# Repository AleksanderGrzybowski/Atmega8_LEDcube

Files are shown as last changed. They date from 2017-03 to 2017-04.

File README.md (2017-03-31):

This is a 4x4x4 LED cube made just for the fun of creating it. Cube has been built using the cheapest LEDs on tme.eu, 64 of them, multiplexed: 16 N-driven columns and 4 P-driven layers. Maximum constant and actual diode current is ~50 mA, which makes sure that they won't fail even when multiplexing hangs in the middle while programming. Driver board is made with 3 '595 shift registers, CPU board is using typical Atmega8 family chip.

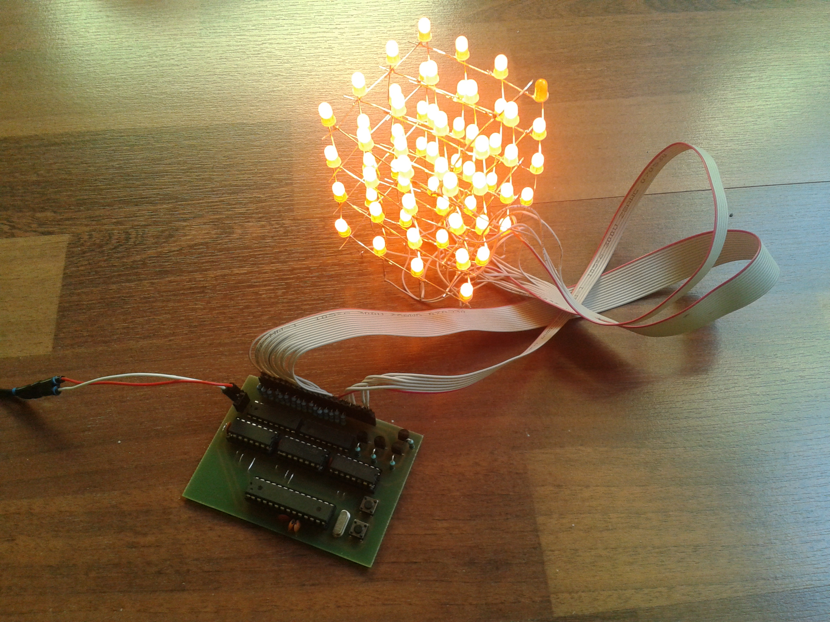
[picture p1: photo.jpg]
Photo of working thing

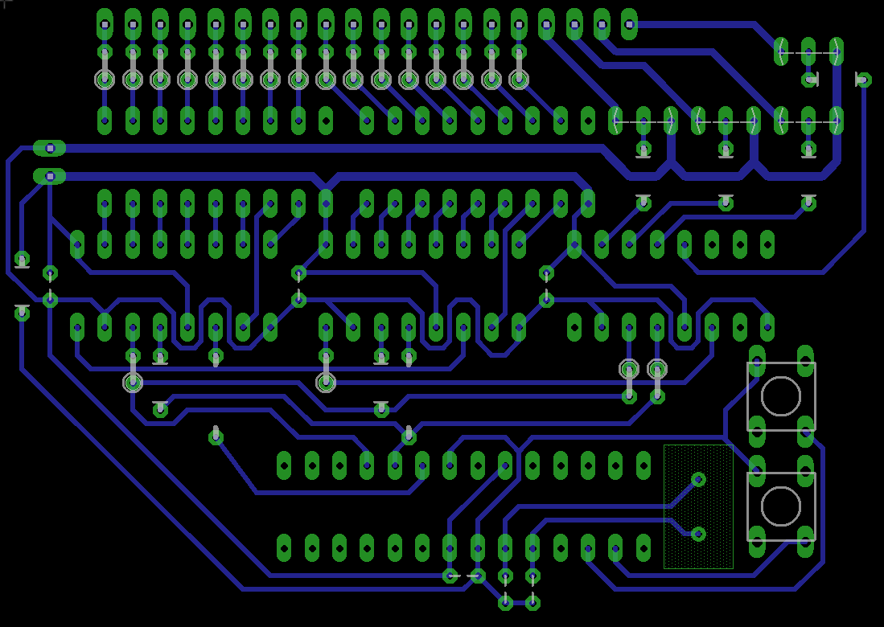
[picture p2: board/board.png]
Board


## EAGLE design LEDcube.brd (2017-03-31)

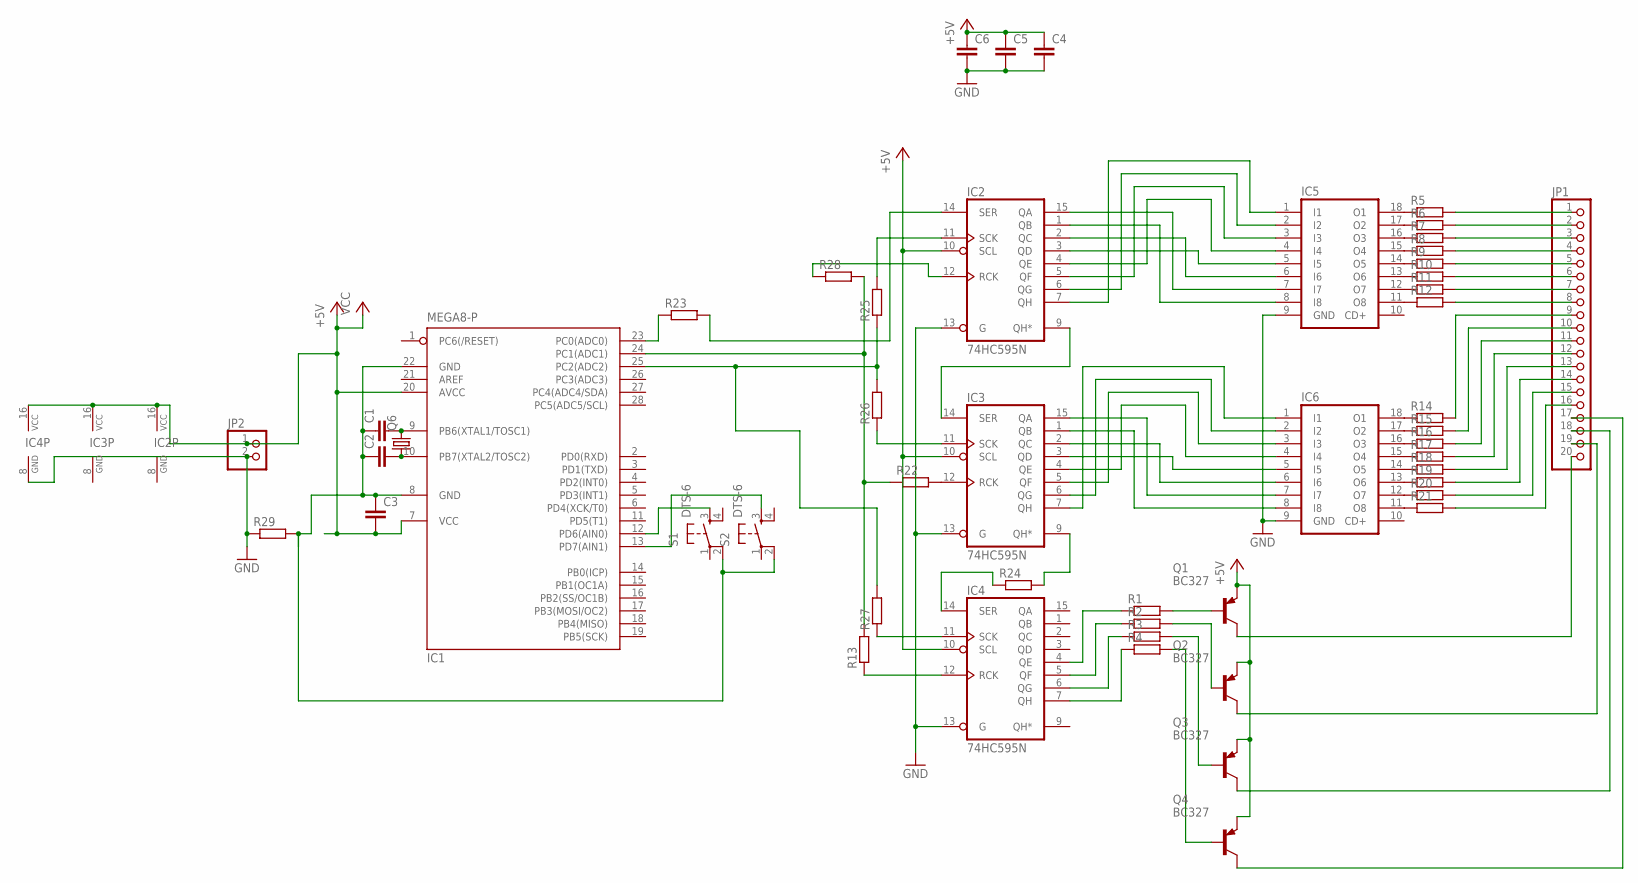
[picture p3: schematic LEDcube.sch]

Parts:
C1, C2, C3, C4, C5, C6: C-EU025-024X044; C025-024X044
IC1: MEGA8-P; DIL28-3
IC2, IC3, IC4: 74HC595N; DIL16
IC5, IC6: ULN2803A; DIL18
JP1: PINHD-1X20; 1X20
JP2: PINHD-1X2; 1X02
Q1, Q2, Q3, Q4: BC327; TO92-EBC
Q6: CRYSTALHC18U-V; HC18U-V
R1, R2, R3, R4, R26, R28, R29: R-EU_0204/5; 0204/5
R5, R6, R7, R8, R9, R10, R11, R12, R13, R14, R15, R16, R17, R18, R19, R20, R21, R24, R25, R27: R-EU_0204/2V; 0204V
R22, R23: R-EU_0204/7; 0204/7
S1, S2: DTS-6

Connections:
+5V: C3.2, C4.1, C5.1, C6.1, IC1.7 (VCC), IC1.20 (AVCC), IC2.10 (SCL), IC2.16 (VCC), IC3.10 (SCL), IC3.16 (VCC), IC4.10 (SCL), IC4.16 (VCC), JP2.1, Q1.E, Q2.E, Q3.E, Q4.E
GND: C4.2, C5.2, C6.2, IC2.8 (GND), IC2.13 (G), IC3.8 (GND), IC3.13 (G), IC4.8 (GND), IC4.13 (G), IC5.9 (GND), IC6.9 (GND), JP2.2, R29.1
GND2: C1.1, C2.1, C3.1, IC1.8 (GND), IC1.22 (GND), R29.2, S1.2, S2.2
unnamed: C1.2, IC1.9 (PB6(XTAL1/TOSC1)), Q6.2
unnamed: C2.2, IC1.10 (PB7(XTAL2/TOSC2)), Q6.1
unnamed: IC4.7 (QH), R4.1
unnamed: IC4.6 (QG), R3.1
unnamed: IC4.5 (QF), R2.1
unnamed: IC2.14 (SER), R23.2
unnamed: IC2.9 (QH*), IC3.14 (SER)
unnamed: IC4.14 (SER), R24.1
unnamed: IC1.12 (PD6(AIN0)), S1.3
unnamed: IC1.24 (PC1(ADC1)), R13.2, R22.1, R28.2
unnamed: IC3.9 (QH*), R24.2
unnamed: IC2.1 (QB), IC5.8 (I8)
unnamed: IC2.15 (QA), IC5.7 (I7)
unnamed: IC2.2 (QC), IC5.6 (I6)
unnamed: IC2.3 (QD), IC5.5 (I5)
unnamed: IC2.4 (QE), IC5.4 (I4)
unnamed: IC2.5 (QF), IC5.3 (I3)
unnamed: IC2.6 (QG), IC5.2 (I2)
unnamed: IC2.7 (QH), IC5.1 (I1)
unnamed: IC3.1 (QB), IC6.8 (I8)
unnamed: IC3.15 (QA), IC6.7 (I7)
unnamed: IC3.2 (QC), IC6.6 (I6)
unnamed: IC3.3 (QD), IC6.5 (I5)
unnamed: IC3.4 (QE), IC6.4 (I4)
unnamed: IC3.5 (QF), IC6.3 (I3)
unnamed: IC3.6 (QG), IC6.2 (I2)
unnamed: IC4.4 (QE), R1.1
unnamed: Q1.B, R1.2
unnamed: Q2.B, R2.2
unnamed: Q3.B, R3.2
unnamed: Q4.B, R4.2
unnamed: IC5.18 (O1), R5.1
unnamed: IC5.17 (O2), R6.1
unnamed: IC5.16 (O3), R7.1
unnamed: IC5.15 (O4), R8.1
unnamed: IC5.14 (O5), R9.1
unnamed: IC5.13 (O6), R10.1
unnamed: IC5.12 (O7), R11.1
unnamed: IC5.11 (O8), R12.1
unnamed: JP1.1, R5.2
unnamed: IC6.18 (O1), R14.1
unnamed: IC6.17 (O2), R15.1
unnamed: IC6.16 (O3), R16.1
unnamed: IC6.15 (O4), R17.1
unnamed: IC6.14 (O5), R18.1
unnamed: IC6.13 (O6), R19.1
unnamed: IC6.12 (O7), R20.1
unnamed: IC6.11 (O8), R21.1
unnamed: JP1.2, R6.2
unnamed: JP1.3, R7.2
unnamed: JP1.4, R8.2
unnamed: JP1.5, R9.2
unnamed: JP1.6, R10.2
unnamed: JP1.7, R11.2
unnamed: JP1.8, R12.2
unnamed: JP1.9, R14.2
unnamed: JP1.10, R15.2
unnamed: JP1.11, R16.2
unnamed: JP1.12, R17.2
unnamed: JP1.13, R18.2
unnamed: JP1.14, R19.2
unnamed: JP1.15, R20.2
unnamed: JP1.16, R21.2
unnamed: JP1.20, Q1.C
unnamed: JP1.19, Q2.C
unnamed: JP1.18, Q3.C
unnamed: JP1.17, Q4.C
unnamed: IC3.7 (QH), IC6.1 (I1)
unnamed: IC1.25 (PC2(ADC2)), R25.1, R26.2, R27.2
unnamed: IC1.13 (PD7(AIN1)), S2.3
unnamed: IC1.23 (PC0(ADC0)), R23.1
unnamed: IC4.11 (SCK), R27.1
unnamed: IC3.12 (RCK), R22.2
unnamed: IC2.12 (RCK), R28.1
unnamed: IC4.12 (RCK), R13.1
unnamed: IC3.11 (SCK), R26.1
unnamed: IC2.11 (SCK), R25.2

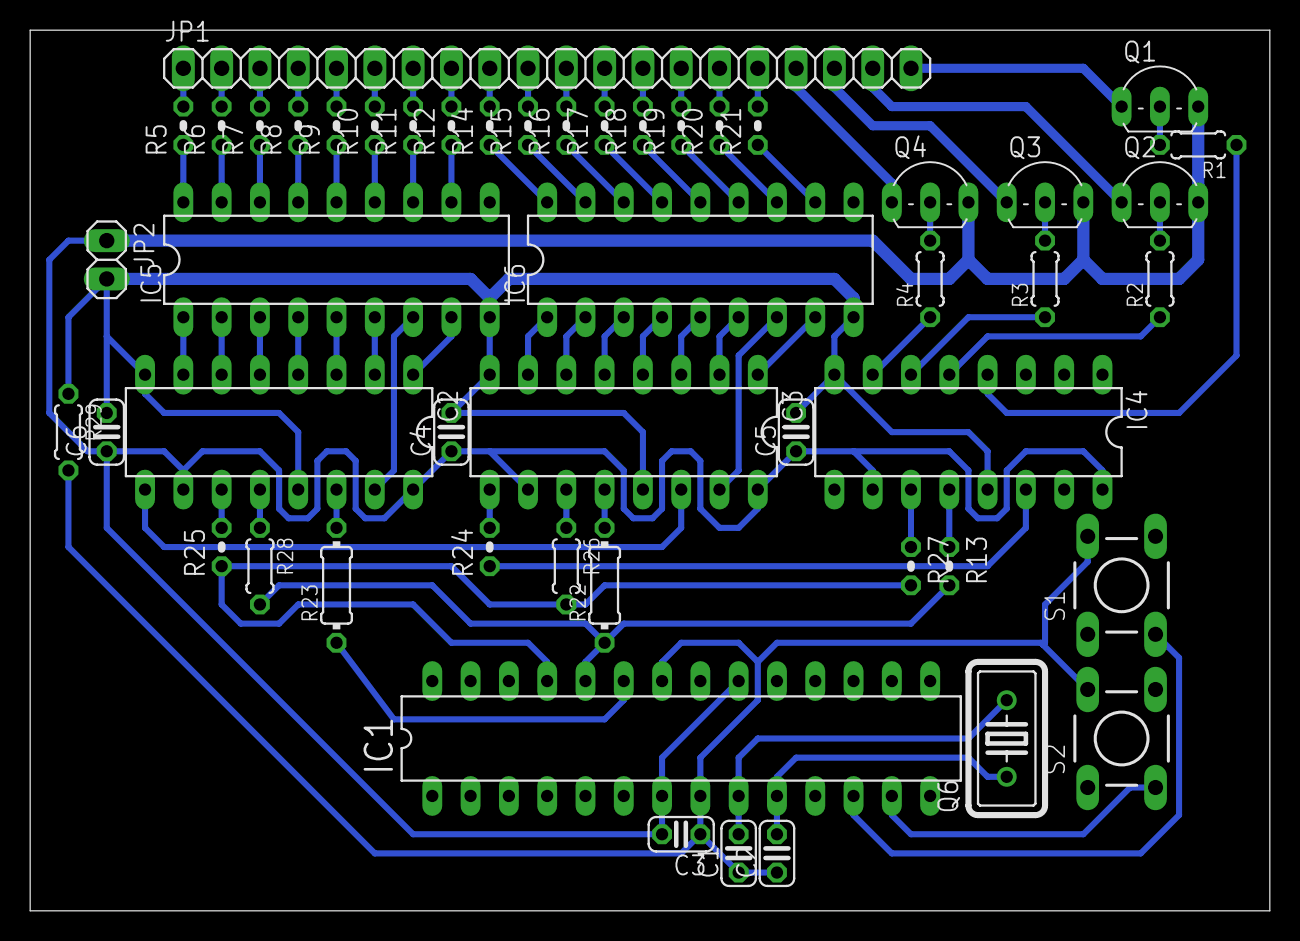
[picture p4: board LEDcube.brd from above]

Board: 2 copper layers, 82.2 x 58.4 mm, 50 parts (0 on the bottom side), 80 nets.

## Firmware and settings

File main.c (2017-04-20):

#include <avr/io.h>
#include <util/delay.h>
#include <avr/interrupt.h>
#include <avr/sleep.h>

#include "595.h"

void delay_ms(uint16_t count) {
    while (count--) {
        _delay_ms(1);
    }
}
void delay_us(uint16_t count) {
    while (count--) {
        _delay_us(1);
    }
}

/* Multiplexing */

typedef struct cube_t {
    char tab[4][16]; // 4 layers, 16 in each layer
} cube_t;

cube_t cube;
volatile int current_layer = 0;
volatile int pwm_iter = 0;

/* Pushing data to shift registers. There are 3 74595's
 * connected in series (Qs - DS), two of them drive 16 N-transistors
 * that turn on vertical columns, one of them drives P-transistors
 * that turn on layers.
 */

ISR(TIMER0_OVF_vect) {
    TCNT0 = 210;
    // TEST ROUTINE, WORKS:
    //    cur++;
    //    transmit(cur);
    //    transmit(2);
    //    commit();

    // 'ripple' through
    pwm_iter++;
    if (pwm_iter == 16) {
        pwm_iter = 0;
        current_layer++;
    }
    if (current_layer == 4) {
        current_layer = 0;
    }

    // layers
    char tosend_pmos = 0xff;
    tosend_pmos &= ~(16 << current_layer); // P-transistors active-low

    // columns
    char tosend_left = 0, tosend_right = 0;

    // split into two loops for two shift registers
    int r;
    for (r = 0; r < 8; ++r) {
        if (cube.tab[current_layer][r] > pwm_iter)
            tosend_left |= (1 << r);
    }
    for (r = 8; r < 16; ++r) {
        if (cube.tab[current_layer][r] > pwm_iter)
            tosend_right |= (1 << (r - 8));
    }

    // push data in the right sequence
    transmit(tosend_pmos);
    transmit(tosend_right);
    transmit(tosend_left);
    commit();
}

void set1(int layer, int pos) {
    cube.tab[layer][pos] = 16;
}

void set0(int layer, int pos) {
    cube.tab[layer][pos] = 0;
}

void set(int layer, int pos, int brig) {
    cube.tab[layer][pos] = brig;
}

void fill(int brig) {
    int i, j;
    for (i = 0; i < 4; ++i) {
        for (j = 0; j < 16; ++j) {
            set(i, j, brig);
        }
    }
}

void set_layer(int layer, int brig) {
    int i;
    for (i = 0; i < 16; ++i) {
        cube.tab[layer][i] = brig;
    }
}

#define TEST_DELAY 30

void test_all() {
    int i, j;

    fill(0);

    for (i = 0; i < 4; ++i) {
        for (j = 0; j < 16; ++j) {
            set1(i, j);
            delay_ms(TEST_DELAY);
            set0(i, j);
        }
    }

    fill(15);

    for (i = 0; i < 4; ++i) {
        for (j = 0; j < 16; ++j) {
            set0(i, j);
            delay_ms(TEST_DELAY);
            set1(i, j);
        }
    }

    fill(0);

    for (i = 0; i < 4; ++i) {
        for (j = 0; j < 16; ++j) {
            set1(i, j);
        }
        delay_ms(TEST_DELAY * 10);
    }

    for (i = 0; i < 4; ++i) {
        for (j = 0; j < 16; ++j) {
            set0(i, j);
        }
        delay_ms(TEST_DELAY * 10);
    }

    fill(15);
    delay_ms(2000);
    fill(0);
}

void e_full_bright() {
    fill(15);
}
void e_little_bright() {
    fill(1);
}

void e_smooth_dimming(int count, int delay) {
    int i, c;
    for (c = 0; c < count; c++) {
        for (i = 0; i < 4; ++i) {
            fill(i);
            delay_ms(delay);
        }
        for (i = 4; i >= 0; --i) {
            fill(i);
            delay_ms(delay);
        }
    }

    fill(0);
}

void e_raindrops(int count, int delay) {

    int bright_tab[] = { 1, 2, 5, 15 };

    int c, i;
    for (c = 0; c < count; c++) {
        int rnd = TCNT1 % 16;
        for (i = 3; i >= 0; --i) {
            set(i, rnd, bright_tab[i]);
            delay_ms(delay);
            set(i, rnd, 0);
        }
    }
}

void e_snake(int count, int delay) {
    int x, y, z;
    int spos = TCNT1 % 64;
    // three random numbers
    x = spos / 16;
    y = spos / 4 % 4;
    z = spos % 4;

    int i;
    for (i = 0; i < count; ++i) {
        int rnd = TCNT1 % 6;

        switch (rnd) {
        case 0: // to the left
            x--;
            if (x == -1)
                x = 1;
            break;
        case 1: // to the right 
            x++;
            if (x == 4)
                x = 2;
            break;
        case 2: // inside 
            y++;
            if (y == 4)
                y = 2;
            break;
        case 3: // outside
            y--;
            if (y == -1)
                y = 1;
            break;
        case 4: // down
            z--;
            if (z == -1)
                z = 1;
            break;
        case 5: // up
            z++;
            if (z == 4)
                z = 2;
            break;
        }
        set1(z, 4 * x + y);
        delay_ms(delay);
        set0(z, 4 * x + y);
    }
}

void e_random(int repeats, int count, int del) {
    fill(0);

    int c, i;
    for (c = 0; c < repeats; ++c) {
        for (i = 0; i < count; ++i) {
            int x, y, z;
            int spos = TCNT1 % 64;
            x = spos / 16;
            y = spos / 4 % 4;
            z = spos % 4;

            set1(z, 4 * x + y);
            delay_ms(del);
        }
        fill(0);
    }
}

int turned_on = 1;
int animation_number = 0;

int main(void) {

    DDRC = 0xff;

    DDRD &= ~(1 << PD6);
    DDRD &= ~(1 << PD7);
    PORTD |= (1 << PD6) | (1 << PD7);


    TIMSK = (1 << TOIE0);
    TCCR0 = (1 << CS01) | (1 << CS00); // 64 works ok
    sei();

    TCCR1B |= (1 << CS12); // kinda RNG

    while (1) {
        if (!(PIND & (1 << PD6))) {
            turned_on = !turned_on;
            fill(0);
            _delay_ms(100);
        }

        if (!(PIND & (1 << PD7))) {
            animation_number++;
            if (animation_number == 3) {
                animation_number = 0;
            }

            _delay_ms(100);
            fill(0);
        }


        if (turned_on) {
            if (animation_number == 0) {
                e_raindrops(1, 20);
            } else if (animation_number == 1) {
                e_smooth_dimming(1, 20);
            } else if (animation_number == 2) {
                e_full_bright();
                _delay_ms(100);
            }
        } else {
            fill(0);
            _delay_ms(100);
        }
    }
}

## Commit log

2017-03-19 Adjust code to new board
2017-03-31 Eagle schematics and finished thing
    [LEDcube.brd, LEDcube.sch]
2017-04-20 Reformat code, simple button handling
